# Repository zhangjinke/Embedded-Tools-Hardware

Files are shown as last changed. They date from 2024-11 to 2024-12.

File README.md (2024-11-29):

## 简介
多功能嵌入式调试工具，特性如下：
* 2 路 CAN 接口；
* 2 路 RS485 接口；
* 1 路 RS232 接口；
* 1 路 UART 接口；
* 1 个 X-Link；
* 1 个 OSJTAG(OSBDM)；
* 1 个 Micro SD 读卡器；
* 1 个 USB 集线器；
* USB 设备端、CAN、RS485、其它接口之间相互隔离；
* 支持拨码选择是否连接 CAN、RS485 的 120Ω 终端电阻；
* X-Link、OSJTAG 支持开关选择 Vref 引脚功能为连接目标板 Vref、输出 3.3V/5V；
* USB 主机、X-Link、OSJTAG 电源输出支持过流、短路以及防电流倒灌功能；

## 实物图
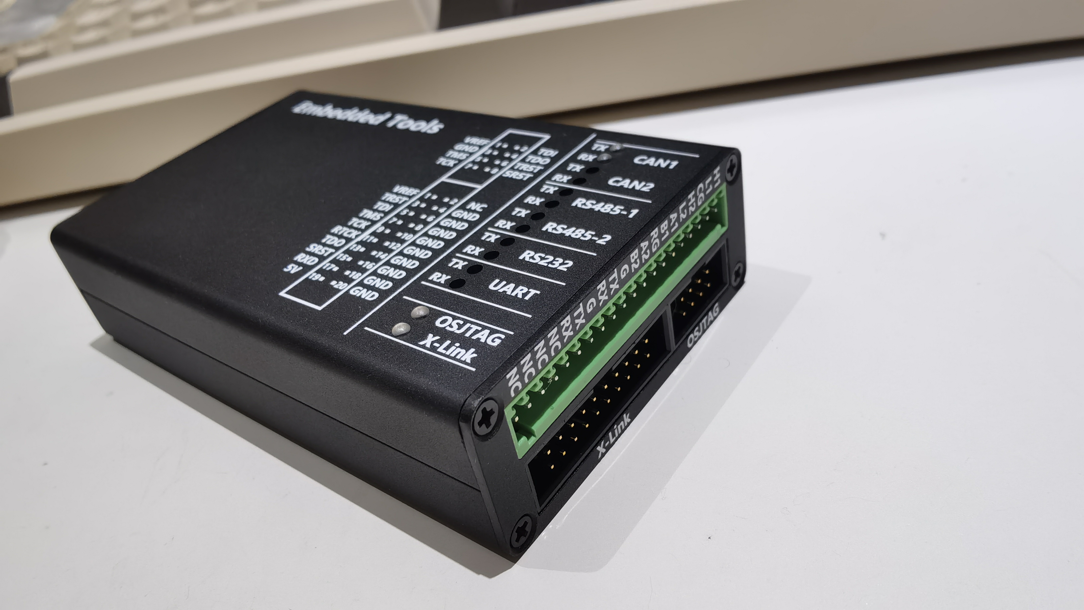
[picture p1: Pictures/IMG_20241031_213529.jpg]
实物图1

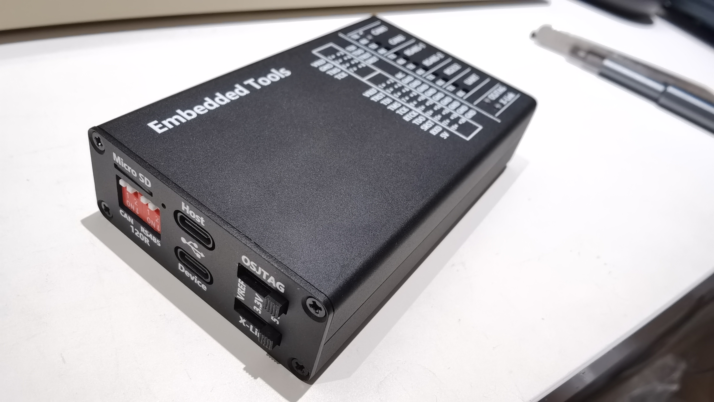
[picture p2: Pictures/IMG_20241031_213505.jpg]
实物图2


## 固件
1. X-Link 目前提供 V9 版模块，固件请在网上自行搜索；
2. OSJTAG 固件开源链接：[osbdm_hpm5301_software](https://github.com/zhangjinke/osbdm_hpm5301_software)；
3. CAN 固件请到 moonglow 大佬仓库搜索 1610 获取，上位机可使用 BUSMASTER。

## 注意事项
1. X-Link、OSJTAG、UART 的 IO 电平范围为 1.65V~5V，且 UART 接口电平与 OSJTAG 电平相同；
2. 连接 2 块主板的 1.27mm 间距，长度 11mm 的排针，请参考 IMG_20241118_211116.jpg 的方式，将长的部分缩短 0.5mm 左右；
3. 电脑端看到的串口 A、B、C、D 分别对应 RS485-1、RS485-2、RS232、UART；
4. 实测 USB 设备端电流 200+mA，若无法使用，请确保 USB 线质量与 USB 口供电能力；
3. USB 设备端隔离由于成本较高，可通过 0R 电阻替代；
4. SGM7222 为预留器件，请勿焊接。通过 R46、R47 焊接 0R 电阻替代。

## 后续计划
1. 增加 Linux 核心板、触摸显示屏、电池，实现离线烧录、升级、调试功能；
2. 增加 OSJTAG 固件功能，比如 DAPLink、USB 转 I2C、USB 转 SPI，模拟 2232 等；
3. 增加更多的 X-Link 模块。

## 声明
1. 您可以自由地对本项目进行修改和二次开发，但请务必在您的作品中注明原作者及原项目链接；
2. 本项目仅供个人、教育和非商业使用。**任何商业用途均需获得作者的事先书面许可**。

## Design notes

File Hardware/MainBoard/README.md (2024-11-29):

## 工程说明
使用嘉立创 EDA 专业版绘制。

## 更新日志

### 24/11/13 (V1.1.1)
- CH344Q RS485 RTC 上拉电阻 R17、R18 阻值从 100K 修改为 4.7K，修复 RTC 引脚未被配置为 RTC 功能，导致该引脚一直输出高电平的问题。

### 24/11/02 (V1.1)
1. 修复 Type-C 接口 DM、DP 反了的问题；
2. OSJTAG 通过增加 R52 修复运放输出震荡的问题，修复晶体负载电容 C4、C5 容值错误问题；
3. UART RX 上拉电阻 R29 从 100K 修改为 10K，降低被干扰的概率；
4. Communication PCB 宽度从 59.9mm 修改为 57.5mm，修复导光柱安装完成后，PCB 无法拆卸的问题；
5. X-Link&OSBDM PCB 在外壳卡槽内的区域，将丝印层修改为阻焊层，避免滑入卡槽内时丝印被刮脱落。

### 24/10/02 (V1.0)
- 初版。

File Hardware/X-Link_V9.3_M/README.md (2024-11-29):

## 工程说明
使用嘉立创 EDA 专业版绘制。

## 更新日志

### 24/11/03 (V1.0.1)
1. D3 修改为 BAT54C，Q2 修改为 KY6801，降低成本；
2. 注明 LED 型号。

### 24/11/04 (V1.0)
- 初版。

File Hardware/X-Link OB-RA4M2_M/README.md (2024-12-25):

## 工程说明
使用嘉立创 EDA 专业版绘制。

## 更新日志

### 24/12/25 (V1.1)
- 修复 MCU_SRST 未连接的问题。

### 24/12/16 (V1.0)
- 初版。

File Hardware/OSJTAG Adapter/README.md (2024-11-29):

## 工程说明
使用嘉立创 EDA 专业版绘制。

## 更新日志

### 24/11/13 (V1.1)
- 修复与上层端子干涉的问题。

### 24/11/02 (V1.0)
- 初版。

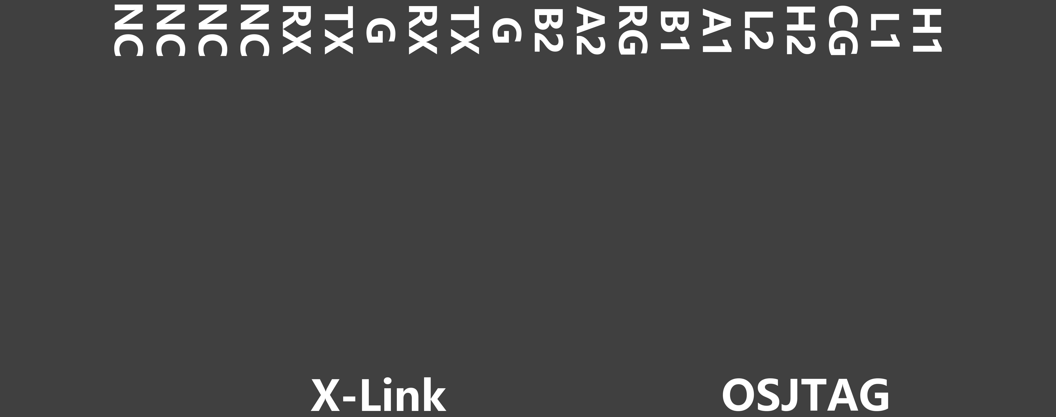
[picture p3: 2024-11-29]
Hardware/外壳/贴图/后面板贴图.png

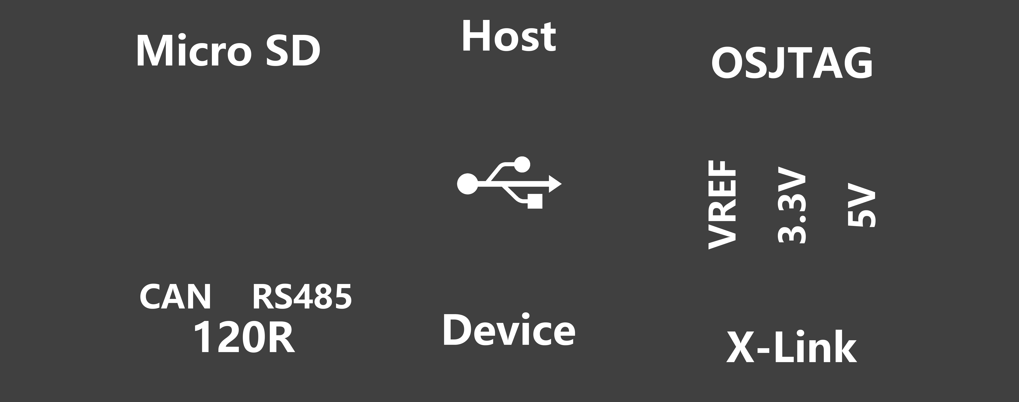
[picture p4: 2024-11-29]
Hardware/外壳/贴图/前面板贴图.png

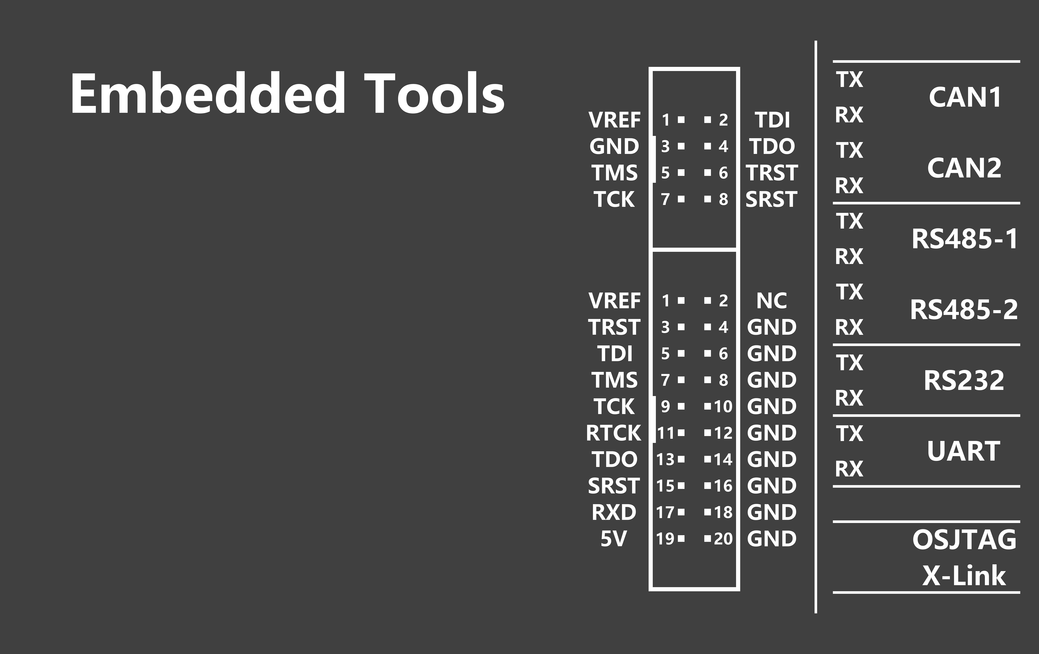
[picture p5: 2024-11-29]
Hardware/外壳/贴图/顶面贴图.png

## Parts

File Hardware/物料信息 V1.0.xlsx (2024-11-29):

No. | Quantity | 5套数量 | Comment | Footprint | Value | Designator | ManufacturerPart | Manufacturer | SupplierPart | Supplier | 焊接品牌 | 焊接型号 | 供应商 | 单价 | 价格
1 | 1 | 5 | 12MHz | CRYSTAL-SMD_4P-L2.5-W2.0-BL-A | 12MHz | X2 |  |  |  |  | 深圳市优信电子科技有限公司 | 12MHz ±10ppm 20pF 3225 | http://e.tb.cn/h.gG8uhOBYo26K7Oo?tk=8sAl39gV1uV | 0.19 | 0.19
2 | 1 | 5 | 12MHz | CRYSTAL-SMD_4P-L2.5-W2.0-BL-A | 12MHz | X3 |  |  |  |  | 深圳市优信电子科技有限公司 | 12MHz ±10ppm 20pF 3225 | http://e.tb.cn/h.gG8uhOBYo26K7Oo?tk=8sAl39gV1uV | 0.19 | 0.19
1 | 1 | 5 | 2.2uH | IND-SMD_L2.5-W2.0_MHCHL2520 | 2.2uH | L2 | FTC252012S2R2MBCA | cjiang(长江微电) | C5832372 |  | / | / | 立创商城 | 0.23256 | 0.23256
2 | 2 | 10 | 2.2uH | IND-SMD_L2.5-W2.0_MHCHL2520 | 2.2uH | L1,L2 | FTC252012S2R2MBCA | cjiang(长江微电) | C5832372 |  | / | / | 立创商城 | 0.23256 | 0.46512
1 | 1 | 5 | 24MHz | CRYSTAL-SMD_4P-L2.0-W1.6-BL-A | 24MHz | X1 |  |  |  |  | 扬兴晶振 | X201624MMB4SI | http://e.tb.cn/h.gG8tK4h0vi460dB?tk=m5nc39gWtUw | 0.26 | 0.26
1 | 1 | 5 | 4.7uH | IND-SMD_L2.5-W2.0 | 4.7uH | L1 | SWPA252012S4R7MT | Sunlord(顺络) | C87640 |  | 长江微电 | FTC252010S4R7MBCA | 立创商城 | 0.2182 | 0.2182
2 | 1 | 5 | 74HC245KAJ | TSSOP-20_L6.5-W4.4-P0.65-LS6.4-BL |  | U5 | 74HC245KAJ | FM(富满) | C19192982 |  | / | / | 立创商城 | 0.2686 | 0.2686
1 | 6 | 30 | 74LVC1T45DW-7 | SC-70-6_L2.2-W1.3-P0.65-LS2.1-BR |  | U4,U5,U6,U7,U8,U9 | 74LVC1T45DW-7 | DIODES(美台) | C168855 |  | / | / | 立创商城 | 0.3829 | 2.2974
2 | 2 | 10 | 74LVC1T45DW-7 | SC-70-6_L2.2-W1.3-P0.65-LS2.1-BR |  | U10,U11 | 74LVC1T45DW-7 | DIODES(美台) | C168855 |  | / | / | 立创商城 | 0.3829 | 0.7658
2 | 2 | 10 | 8MHz | CRYSTAL-SMD_4P-L3.2-W2.5-BL-A | 8MHz | X1,X2 |  |  |  |  | 创捷 | RL080002265 | 立创商城 | 0.3382 | 0.6764
2 | 1 | 5 | AO3401A | SOT-23_L2.9-W1.3-P1.90-LS2.4-BR |  | Q1 | AO3401A | AOS | C15127 |  | 杰盛微 | JSM2301S | 立创商城 | 0.050915 | 0.050915
2 | 2 | 10 | B0505S-1WR3 | PWRM-TH_B0503S-1WR2_S_1 |  | U4,U8 | B0505S-1WR3 | MORNSUN(金升阳) | C131038 |  |  |  |  | 2.52 | 5.04
3 | 1 | 5 | BAR43CFILM | SOT-23-3_L2.9-W1.3-P1.90-LS2.4-BR |  | D3 | BAR43CFILM | ST(意法半导体) | C69290 |  | 杰盛微 | BAT54C | 立创商城 | 0.042423 | 0.042423
2 | 6 | 30 | BLUE | LED0603 |  | LED1,LED3,LED6,LED8,LED10,LED12 |  |  |  |  | 成兴光 | XL-1608UBC-04 | 立创商城 | 0.02034 | 0.12204
2 | 1 | 5 | BX-PM1.27-2-5PU | HDR-TH_10P-P1.27-V-F-R2-C5-S1.27_1 |  | P2 | BX-PM1.27-2-5PU | Bossie(博锡) | C18078163 |  | 深圳市优信电子科技有限公司 | 1.27 双排母 2*50P | http://e.tb.cn/h.gGBZZw8JrdaCuqG?tk=1dFH395rqjm | 0.275 | 0.275
2 | 1 | 5 | CA-IS3742HB | SSOP-16_L4.9-W3.9-P0.64-LS6.0-BL |  | U3 | CA-IS3742HB | Chipanalog(川土微) | C7370896 |  | / | / | 立创商城 | 3.47 | 3.47
2 | 1 | 5 | CA-IS3762HB | SSOP-16_L4.9-W3.9-P0.64-LS6.0-BL-1 |  | U7 | CA-IS3762HB | Chipanalog(川土微) | C19723482 |  | / | / | 立创商城 | 5.06 | 5.06
1 | 1 | 5 | CH334R | QSOP-16_L4.9-W3.9-P0.64-LS6.0-BL |  | U10 | CH334R | WCH(南京沁恒) | C4154405 |  | / | / | http://e.tb.cn/h.gtD9xLTc9HWW0nF?tk=pGPC39gR36E | 1.5 | 1.5
2 | 1 | 5 | CH334R | QSOP-16_L4.9-W3.9-P0.64-LS6.0-BL |  | U19 | CH334R | WCH(南京沁恒) | C4154405 |  | / | / | http://e.tb.cn/h.gtD9xLTc9HWW0nF?tk=pGPC39gR36E | 1.5 | 1.5
2 | 1 | 5 | CH344Q | LQFP-48_L7.0-W7.0-P0.50-LS9.0-BL |  | U6 | CH344Q | WCH(南京沁恒) | C2988084 |  | / | / | http://e.tb.cn/h.gGYxo0BpgagSMRt?tk=JBjL39giDhR | 10.27 | 10.27
2 | 1 | 5 | ESDA5V3L | SOT-23-3_L2.9-W1.6-P1.90-LS2.8-BR |  | U15 | ESDA5V3L |  |  |  | ST | ESDA6V1L | 立创商城 | 0.5332 | 0.5332
3 | 1 | 5 | FDC6312P | SOT-23-6_L2.9-W1.6-P0.95-LS2.8-BR |  | Q2 | FDC6312P | onsemi(安森美) | C241767 |  | 韩景元 | KY6801 | 立创商城 | 0.2354 | 0.2354
2 | 12 | 60 | FUSE0805 | F0805 |  | F1,F2,F3,F4,F5,F6,F7,F8,F9,F10,F11,F12 |  |  |  |  | 比诺星 | SMD0805-010C-15V | 立创商城 | 0.10412 | 1.24944
2 | 1 | 5 | GL823K-HCY04 | SSOP-16_L4.9-W3.9-P0.64-LS6.0-BL |  | U18 | GL823K-HCY04 | GENESYS(创惟) | C284879 |  | / | / | http://e.tb.cn/h.gGYxcwATD4O97e4?tk=jXfs39gi9vk MF7997 | 1.15 | 1.15
2 | 1 | 5 | HDR1x5_1.27 | HDR-TH_5P-P1.27-V-M |  | P1 |  |  |  |  |  |  |  |  | 0
3 | 1 | 5 | HDR1x5_1.27 | HDR-TH_5P-P1.27-V-M |  | P3 |  |  |  |  |  |  |  |  | 0
1 | 1 | 5 | HDR1x7_1.27 | HDR-TH_7P-P1.27-V-M-1 |  | P3 |  |  |  |  |  |  |  |  | 0
3 | 1 | 5 | HDR2x10_1.27 | HDR-TH_20P-P1.27-V-M-R2-C10-S1.27 |  | P2 |  |  |  |  | 怡兴达数码专营店 | 间距1.27mm/针长11mm 2*50P | http://e.tb.cn/h.gG8eFk0z1i0zUFU?tk=9gg2395n4TH | 0.72 | 0.72
1 | 1 | 5 | HDR2x10_1.27_SMD | HDR-SMD_20P-P1.27-V-M-R2-C10-LS5.5 |  | P2 |  |  |  |  | 深圳市优信电子科技有限公司 | 双排贴片 镀金 2*50P | http://e.tb.cn/h.gGBZZw8JrdaCuqG?tk=1dFH395rqjm | 0.24 | 0.24
1 | 2 | 10 | HDR2x16_1.27 | HDR-TH_32P-P1.27-V-M-R2-C16-S1.27 |  | U15,U16 |  |  |  |  | 怡兴达数码专营店 | 间距1.27mm/针长11mm 2*50P | http://e.tb.cn/h.gG8eFk0z1i0zUFU?tk=9gg2395n4TH | 1.2 | 2.4
1 | 1 | 5 | HDR2x5_1.27_1 | HDR-TH_10P-P1.27-V-M-R2-C5-S1.27_1 |  | P4 |  |  |  |  | 怡兴达数码专营店 | 间距1.27mm/针长11mm 2*50P | http://e.tb.cn/h.gG8eFk0z1i0zUFU?tk=9gg2395n4TH | 0.36 | 0.36
3 | 1 | 5 | HDR2x8_1.27 | HDR-TH_16P-P1.27-V-M-R2-C8-S1.27-1 |  | P1 |  |  |  |  | 怡兴达数码专营店 | 间距1.27mm/针长11mm 2*50P | http://e.tb.cn/h.gG8eFk0z1i0zUFU?tk=9gg2395n4TH | 0.6 | 0.6
1 | 1 | 5 | HDR2x8_1.27_SMD | HDR-SMD_16P-P1.27-V-M-R2-C8-LS5.5 |  | P1 |  |  |  |  | 深圳市优信电子科技有限公司 | 双排贴片 镀金 2*50P | http://e.tb.cn/h.gGBZZw8JrdaCuqG?tk=1dFH395rqjm | 0.2 | 0.2
1 | 1 | 5 | HPM5301IEG1 | QFN-48_L6.0-W6.0-P0.4-BL-EP4.2 |  | U2 |  |  |  |  | / | / | http://e.tb.cn/h.gG8zsUPNutN8KXw?tk=Koz539g77Q9 | 8.5 | 8.5
1 | 1 | 5 | IDC2x10_SMD | IDC-SMD_20P-P2.54 |  | P6 |  |  |  |  | 精工南士 | DC3-20P 直针 简牛 | http://e.tb.cn/h.gtD8Dcz8nh2YK2G?tk=6Xnf39ghhj2 | 0.8 | 0.8
1 | 1 | 5 | IDC2x4_SMD | IDC-SMD_8P-P2.54 |  | P5 |  |  |  |  | 精工南士 | DC3-8P 直针 简牛 | http://e.tb.cn/h.gGBqdUiuMef7D32?tk=knkB39gTxVA | 1 | 1
1 | 1 | 5 | ISOUSB211DPR | SSOP-28_L10.3-W7.5-P0.65-LS10.3-BL |  | U12 | ISOUSB211DPR | TI(德州仪器) | C5772877 |  | / | / | https://www.zxjian.com/search?searchContent=ISOUSB211DPR | 34.32 | 34.32
2 | 1 | 5 | KF2EDGV-2.5-20P | CONN-TH_20P-P2.50_KF2EDGV-2.5-20P_SMD |  | CN1 | KF2EDGV-2.5-20P | KEFA(科发) |  |  | / | / | http://e.tb.cn/h.gGBpbUBK6ho59aD?tk=On6O39gg8iQ | 9 | 9
1 | 1 | 5 | LED1615 | LED1615 |  | D1 |  |  |  |  |  |  |  | 0.1 | 0.1
2 | 2 | 10 | LED1615 | LED1615 |  | D5,D6 |  |  |  |  |  |  |  | 0.1 | 0.2
3 | 1 | 5 | LED1615 | LED1615 |  | D1 |  |  |  |  |  |  |  | 0.1 | 0.1
2 | 1 | 5 | LMV358AIDGKR | VSSOP-8_L3.0-W3.0-P0.65-LS5.0-BL |  | U19 | LMV358AIDGKR | TI(德州仪器) | C408974 |  | / | / | 立创商城 | 0.363675 | 0.363675
2 | 1 | 5 | LMV358AIDGKR | VSSOP-8_L3.0-W3.0-P0.65-LS5.0-BL |  | U24 | LMV358AIDGKR | TI(德州仪器) | C408974 | LCSC | / | / | 立创商城 | 0.363675 | 0.363675
3 | 1 | 5 | LMV358AIDGKR | VSSOP-8_L3.0-W3.0-P0.65-LS5.0-BL |  | U9 | LMV358AIDGKR | TI(德州仪器) | C408974 |  | / | / | 立创商城 | 0.363675 | 0.363675
1 | 4 | 20 | NC | R1206 | NC | R42,R43,R44,R45 |  |  |  |  |  |  |  |  | 0
1 | 2 | 10 | NC | R0402 | NC | R46,R47 |  |  |  |  |  |  |  |  | 0
3 | 1 | 5 | NC | R0603 | NC | R47 |  |  |  |  |  |  |  |  | 0
2 | 2 | 10 | PM1.27-2x16 | HDR-TH_32P-P1.27-V-F-R2-C16-S1.27 |  | P3,P4 |  |  |  |  | 深圳市优信电子科技有限公司 | 1.27 双排母 2*50P | http://e.tb.cn/h.gGBZZw8JrdaCuqG?tk=1dFH395rqjm | 1.1 | 2.2
2 | 1 | 5 | SDT23C712L02 | SOT-23-3_L2.9-W1.6-P1.90-LS2.8-BR |  | U14 | SDT23C712L02 |  |  |  | KUU | SM15C | 立创商城 | 0.24225 | 0.24225
2 | 1 | 5 | SGM7222YMS10/TR | MSOP-10_L3.0-W3.0-P0.50-LS5.0-BL |  | U14 | SGM7222YMS10/TR | SGMICRO(圣邦微) | C113292 |  | / | / | http://e.tb.cn/h.gGYKvP2s6YJ0WTn?tk=oXOS39gW0AS | 0.89 | 0.89
1 | 1 | 5 | SI2302A | SOT-23-3_L2.9-W1.3-P1.90-LS2.4-BR |  | Q1 | SI2302A | UMW(友台半导体) | C347483 |  | 杰盛微 | JSM2302 | 立创商城 | 0.025185 | 0.025185
2 | 2 | 10 | SIT1057TK/3 | DFN-8_L3.0-W3.0-P0.65-BL-EP-1 |  | U1,U2 | SIT1057TK/3 | SIT(芯力特) | C5382538 |  | / | SIT1044QTK/3 | http://e.tb.cn/h.gG8xwxTs4wh8V0T?tk=FNJl39g52lN | 1.57 | 3.14
2 | 2 | 10 | SIT3088ETK | DFN-8_L3.0-W3.0-P0.65-BL-EP |  | U12,U13 | SIT3088ETK | SIT(芯力特) | C601076 |  | / | / | http://e.tb.cn/h.gtDSMO9yWGzUPp2?tk=eQNd39gU2ci | 0.7 | 1.4
2 | 2 | 10 | SM712 | SOT-23-3_L2.9-W1.6-P1.90-LS2.8-BR |  | U16,U17 | SM712 |  |  |  | 静芯微 | SM712.TCT-ES | 立创商城 | 0.0982 | 0.1964
2 | 2 | 10 | SM712 | SOT-23-3_L2.9-W1.6-P1.90-LS2.8-BR |  | D1,D2 | SM712 | MDD | C502564 |  | 静芯微 | SM712.TCT-ES | 立创商城 | 0.0982 | 0.1964
1 | 2 | 10 | SMQP-02R-TP | SW-TH_4P-P2.54_SMQP-02R-TP |  | U17,U18 | SMQP-02R-TP | SMSwitch | C5299482 |  |  |  |  | 1.7117 | 3.4234
3 | 7 | 35 | SN74LVC2T45DCUR | VSSOP-8_L2.4-W2.1-P0.50-LS3.2-BR |  | U2,U3,U4,U5,U6,U7,U8 | SN74LVC2T45DCUR | TI(德州仪器) | C15741 | LCSC |  |  |  | 1.4 | 9.8
2 | 1 | 5 | SP3232EEY-L/TR | TSSOP-16_L5.0-W4.4-P0.65-LS6.4-BL |  | U9 | SP3232EEY-L/TR | MaxLinear(迈凌) | C13482 |  | / | / | 立创商城 | 1.4102 | 1.4102
1 | 1 | 5 | SS23H37L4 | SW-TH_SS23H37LX_SMD |  | SW1 | SS23H37L4 | XKBConnectivity(中国星坤) | C883268 |  | / | / | 立创商城 | 1.8854 | 1.8854
2 | 1 | 5 | SS23H37L4 | SW-TH_SS23H37LX_SMD |  | SW1 | SS23H37L4 | XKBConnectivity(中国星坤) | C883268 |  | / | / | 立创商城 | 1.8854 | 1.8854
3 | 1 | 5 | STM32F205RCT6 | LQFP-64_L10.0-W10.0-P0.50-LS12.0-BL |  | U1 | STM32F205RCT6 | ST(意法半导体) | C47520 |  |  |  |  | 24 | 24
2 | 1 | 5 | STM32F405RGT6 | LQFP-64_L10.0-W10.0-P0.50-LS12.0-BL |  | U23 | STM32F405RGT6 | ST(意法半导体) | C15742 |  | / | / | http://e.tb.cn/h.gGBNSX9pXcJlqrS?tk=GWVA39gUUjT | 11.97 | 11.97
2 | 2 | 10 | SY6280AAC | SOT-23-5_L3.0-W1.7-P0.95-LS2.8-BL |  | U1,U3 | SY6280AAC | silergy(矽力杰) | C55136 |  | / | / | http://e.tb.cn/h.gGYpF9LmazMhy0t?tk=4L9W39g2rNn | 0.39 | 0.78
2 | 1 | 5 | SY6280AAC | SOT-23-5_L3.0-W1.7-P0.95-LS2.8-BL |  | U22 | SY6280AAC | silergy(矽力杰) | C55136 |  | / | / | http://e.tb.cn/h.gGYpF9LmazMhy0t?tk=4L9W39g3rNn | 0.39 | 0.39
2 | 1 | 5 | TFPUSH | TF-SMD_TF-PUSH |  | CARD1 | TFPUSH | SHOUHAN(首韩) | C393941 |  | / | / | 立创商城 | 0.2953 | 0.2953
1 | 1 | 5 | TLV62568DBVR | SOT-23-5_L3.0-W1.7-P0.95-LS2.8-BR |  | U11 | TLV62568DBVR | TI(德州仪器) | C163219 |  | / | / | http://e.tb.cn/h.gGYoAijcOZGUYAO?tk=V5jb39gXJOI | 0.22 | 0.22
2 | 2 | 10 | TLV62568DBVR | SOT-23-5_L3.0-W1.7-P0.95-LS2.8-BR |  | U20,U21 | TLV62568DBVR | TI(德州仪器) | C163219 |  | / | / | http://e.tb.cn/h.gGYoAijcOZGUYAO?tk=V5jb39gXJOI | 0.22 | 0.44
1 | 1 | 5 | USB31-TYPEC-16X7C-1FS | USB-SMD_USB31-TYPEC-16X7C-1FS |  | USB1 | USB31-TYPEC-16X7C-1FS | XKBConnection(中国星坤) | C2880667 |  | / | / | http://e.tb.cn/h.gtDWSV4pChgk9Iz?tk=zA9P39gcN4s CA6496 | 3.8 | 3.8
2 | 1 | 5 | USB31-TYPEC-16X7C-1FS | USB-SMD_USB31-TYPEC-16X7C-1FS |  | USB1 | USB31-TYPEC-16X7C-1FS | XKBConnection(中国星坤) | C2880667 |  | / | / | http://e.tb.cn/h.gtDWSV4pChgk9Iz?tk=zA9P39gcN4s CA6496 | 3.8 | 3.8
1 | 1 | 5 | USBLC6-2SC6 | SOT-23-6_L2.9-W1.6-P0.95-LS2.8-BL |  | D3 | USBLC6-2SC6 | UMW(友台半导体) | C2687116 |  | 东沃 | USBLC6-2SC6 | 立创商城 | 0.1044 | 0.1044
2 | 1 | 5 | USBLC6-2SC6 | SOT-23-6_L2.9-W1.6-P0.95-LS2.8-BL |  | D4 | USBLC6-2SC6 | UMW(友台半导体) | C2687116 |  | 东沃 | USBLC6-2SC6 | 立创商城 | 0.1044 | 0.1044
1 | 1 | 5 | VRB0505S-5WR3 | PWRM-TH_7P-L22.0-W9.5-P2.54_VRB0505S-5WR3_ST |  | U13 | VRB0505S-5WR3 | MORNSUN(金升阳) | C5189717 |  | kcut旗舰店 | VRB0505S-6WR3 | http://e.tb.cn/h.gGyyCbm65PxT9SJ?tk=wbKx395qVMP | 17.5 | 17.5
2 | 6 | 30 | YELLOW | LED0603 |  | LED2,LED4,LED7,LED9,LED11,LED13 |  |  |  |  | 拓展光电 | TZ-P2-0603YGTCS1-0.6T | 立创商城 | 0.0468 | 0.2808
2 | 1 | 1 | 8P排线 | 1.27 |  |  |  |  |  |  | 深圳致远电子企业店 | 100mm | http://e.tb.cn/h.T23iBy0s1SgjbUQ?tk=RUI63GBSX9R | 0.2 | 0.2
2 | 14 | 70 | 导光柱LDT2.0x6 | 开孔φ1.95-2.0 |  |  |  |  |  |  | 导光柱生产工厂店 | 6mm | http://e.tb.cn/h.T21eHfGMxfLbz30?tk=4rl93GBURiF | 0.22 | 3.08
 | 1 | 5 | 铝型材壳体 | 分体式K30(100x63x25) |  |  |  |  |  |  | 嘉立创FA-铝合金壳体 | 分体式K30(100x63x25) | https://ke.jlcfa.com/share/DAFCFDD64CEA470E9EB28F21D9953762/371638437327007745 访问密码：5T8A【嘉立创FA铝合金壳体】Embedded Tools | 35 | 35
 |  |  |  |  |  |  |  |  |  |  |  |  |  | 总价 | 224.353058 | 172.533058

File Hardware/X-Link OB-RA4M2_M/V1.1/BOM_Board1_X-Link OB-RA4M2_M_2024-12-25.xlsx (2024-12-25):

No. | Quantity | Comment | Footprint | Value | Designator | Manufacturer Part | Manufacturer | Supplier Part | Supplier
1 | 1 | 2.2uF | C0402 | 2.2uF | C8
2 | 2 | 10pF | C0402 | 10pF | C1,C2
3 | 16 | 100nF | C0402 | 100nF | C3,C4,C5,C6,C7,C9,C10,C11,C12,C13,C14,C15,C16,C17,C18,C19
4 | 1 | 12MHz | CRYSTAL-SMD_4P-L2.5-W2.0-BL-A | 12MHz | X1
5 | 1 | HDR1x5_1.27 | HDR-TH_5P-P1.27-V-M |  | P3
6 | 1 | HDR2x8_1.27 | HDR-TH_16P-P1.27-V-M-R2-C8-S1.27-1 |  | P1
7 | 1 | HDR2x10_1.27 | HDR-TH_20P-P1.27-V-M-R2-C10-S1.27 |  | P2
8 | 1 | WHITE | LED0603 |  | LED1
9 | 1 | R7FA4M2AB3CFL#AA0 | LQFP-48_L7.0-W7.0-P0.50-LS9.0-BL |  | U2 | R7FA4M2AB3CFL#AA0 | RENESAS(瑞萨)/IDT | C3230219 | LCSC
10 | 1 | 1K | R0402 | 1K | R14
11 | 6 | 10K | R0402 | 10K | R1,R4,R5,R6,R8,R10
12 | 1 | 12K | R0402 | 12K | R7
13 | 2 | 27R | R0402 | 27R | R2,R3
14 | 7 | 100R | R0402 | 100R | R24,R25,R26,R27,R28,R29,R30
15 | 7 | 200K | R0402 | 200K | R9,R13,R21,R22,R23,R31,R32
16 | 6 | 220R | R0402 | 220R | R15,R16,R17,R18,R19,R20
17 | 1 | NC | R0402 | NC | R11
18 | 1 | 100R | R0805 | 100R | R12
19 | 1 | SN74LVC1G3157DCKR | SC70-6_L2.1-W1.3-P0.65-LS2.3-BL |  | U4 | SN74LVC1G3157DCKR | UMW(友台半导体) | C2681224 | LCSC
20 | 4 | SN74LVC1T45DC(LX) | SC-70-6_L2.2-W1.3-P0.65-LS2.1-BR |  | U6,U7,U8,U9 | SN74LVC1T45DC(LX) | LX(灵星芯微) | C22469932 | LCSC
21 | 1 | 1N5819WT | SOD-523_L1.2-W0.8-LS1.6-RD |  | D1 | 1N5819WT | Slkor(萨科微) | C5185918 | LCSC
22 | 1 | LMV321 | SOT-23-5_L2.9-W1.6-P0.95-LS2.8-BR |  | U3 | LMV321
23 | 1 | SY6280AAC | SOT-23-5_L3.0-W1.7-P0.95-LS2.8-BL |  | U1 | SY6280AAC | silergy(矽力杰) | C55136 | LCSC
24 | 2 | HXY1012CI | SOT-523-3_L1.6-W0.8-P0.50-LS1.6-BR |  | Q1,Q2 | HXY1012CI | HXY MOSFET(华轩阳电子) | C5148644 | LCSC
25 | 1 | PI4ULS5V202XVEX | UDFN-8_L1.6-W1.2-P0.40-BL |  | U10 | PI4ULS5V202XVEX | DIODES(美台) | C2677370 | LCSC

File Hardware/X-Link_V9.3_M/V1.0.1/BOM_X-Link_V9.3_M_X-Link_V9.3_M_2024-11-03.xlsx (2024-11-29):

No. | Quantity | Comment | Footprint | Value | Designator | Manufacturer Part | Manufacturer | Supplier Part | Supplier
1 | 4 | 2.2uF | C0603 | 2.2uF | C8,C9,C11,C16
2 | 2 | 10pF | C0603 | 10pF | C5,C6
3 | 18 | 100nF | C0603 | 100nF | C1,C2,C3,C4,C7,C10,C12,C13,C14,C15,C17,C18,C19,C20,C21,C22,C23,C24
4 | 1 | 12MHz | CRYSTAL-SMD_4P-L3.2-W2.5-BL-A | 12MHz | X1
5 | 1 | HDR1x5_1.27 | HDR-TH_5P-P1.27-V-M |  | P3
6 | 1 | HDR2x8_1.27 | HDR-TH_16P-P1.27-V-M-R2-C8-S1.27-1 |  | P1
7 | 1 | HDR2x10_1.27 | HDR-TH_20P-P1.27-V-M-R2-C10-S1.27 |  | P2
8 | 1 | XL-1615SURSYGC | LED1615 |  | D1 | XL-1615SURSYGC | XINGLIGHT(成兴光) | C965838 | LCSC
9 | 1 | STM32F205RCT6 | LQFP-64_L10.0-W10.0-P0.50-LS12.0-BL |  | U1 | STM32F205RCT6 | ST(意法半导体) | C47520 | LCSC
10 | 2 | 1K | R0603 | 1K | R6,R7
11 | 8 | 2.2K | R0603 | 2.2K | R2,R3,R8,R9,R10,R11,R13,R14
12 | 5 | 10K | R0603 | 10K | R4,R5,R17,R18,R21
13 | 1 | 68R | R0603 | 68R | R37
14 | 5 | 100K | R0603 | 100K | R1,R15,R16,R19,R42
15 | 7 | 100R | R0603 | 100R | R12,R20,R34,R35,R36,R38,R39
16 | 7 | 220K | R0603 | 220K | R43,R44,R45,R46,R48,R49,R50
17 | 12 | 220R | R0603 | 220R | R24,R25,R26,R27,R28,R29,R30,R31,R32,R33,R40,R41
18 | 1 | NC | R0603 | NC | R47
19 | 2 | 1R | R0805 | 1R | R22,R23
20 | 1 | B5819WS | SOD-323_L1.8-W1.3-LS2.5-RD |  | D2 | B5819WS | CJ(江苏长电/长晶) | C22624 | LCSC
21 | 1 | BAT54C | SOT-23-3_L2.9-W1.3-P1.90-LS2.4-BR |  | D3 | BAT54C | JSMSEMI(杰盛微) | C916424 | LCSC
22 | 1 | JSM2302 | SOT-23-3_L2.9-W1.3-P1.90-LS2.4-BR |  | Q1 | JSM2302 | JSMSEMI(杰盛微) | C916403 | LCSC
23 | 1 | KY6801 | SOT-23-6_L2.9-W1.6-P0.95-LS2.8-BR |  | Q2 | KY6801 | KY(韩景元) | C3029283 | LCSC
24 | 7 | SN74LVC2T45DCUR | VSSOP-8_L2.4-W2.1-P0.50-LS3.2-BR |  | U2,U3,U4,U5,U6,U7,U8 | SN74LVC2T45DCUR | TI(德州仪器) | C15741 | LCSC
25 | 1 | LMV358AIDGKR | VSSOP-8_L3.0-W3.0-P0.65-LS5.0-BL |  | U9 | LMV358AIDGKR | TI(德州仪器) | C408974 | LCSC

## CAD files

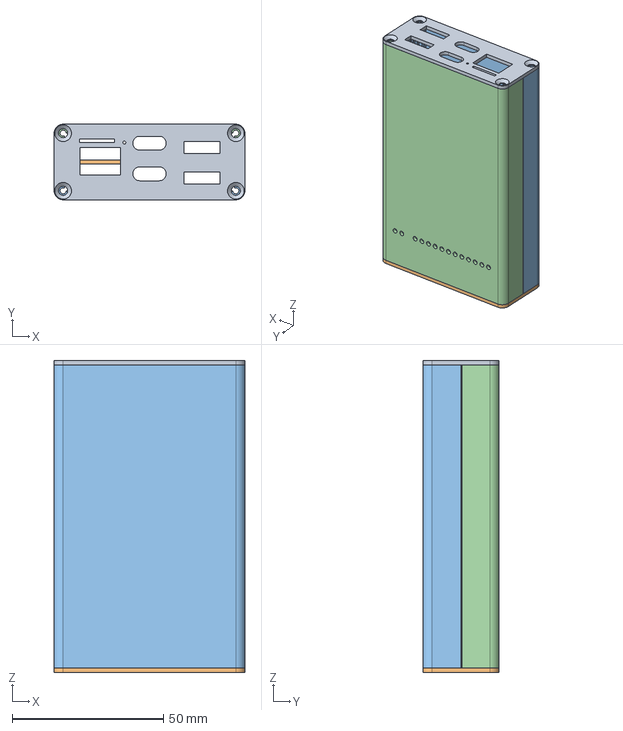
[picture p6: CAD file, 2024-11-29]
Hardware/外壳/分体式K30_1728622400uj7h.stp
63.0 x 25.0 x 103.0 mm

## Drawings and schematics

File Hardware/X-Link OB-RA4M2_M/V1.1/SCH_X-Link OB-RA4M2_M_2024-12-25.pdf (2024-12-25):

# Vref缓冲

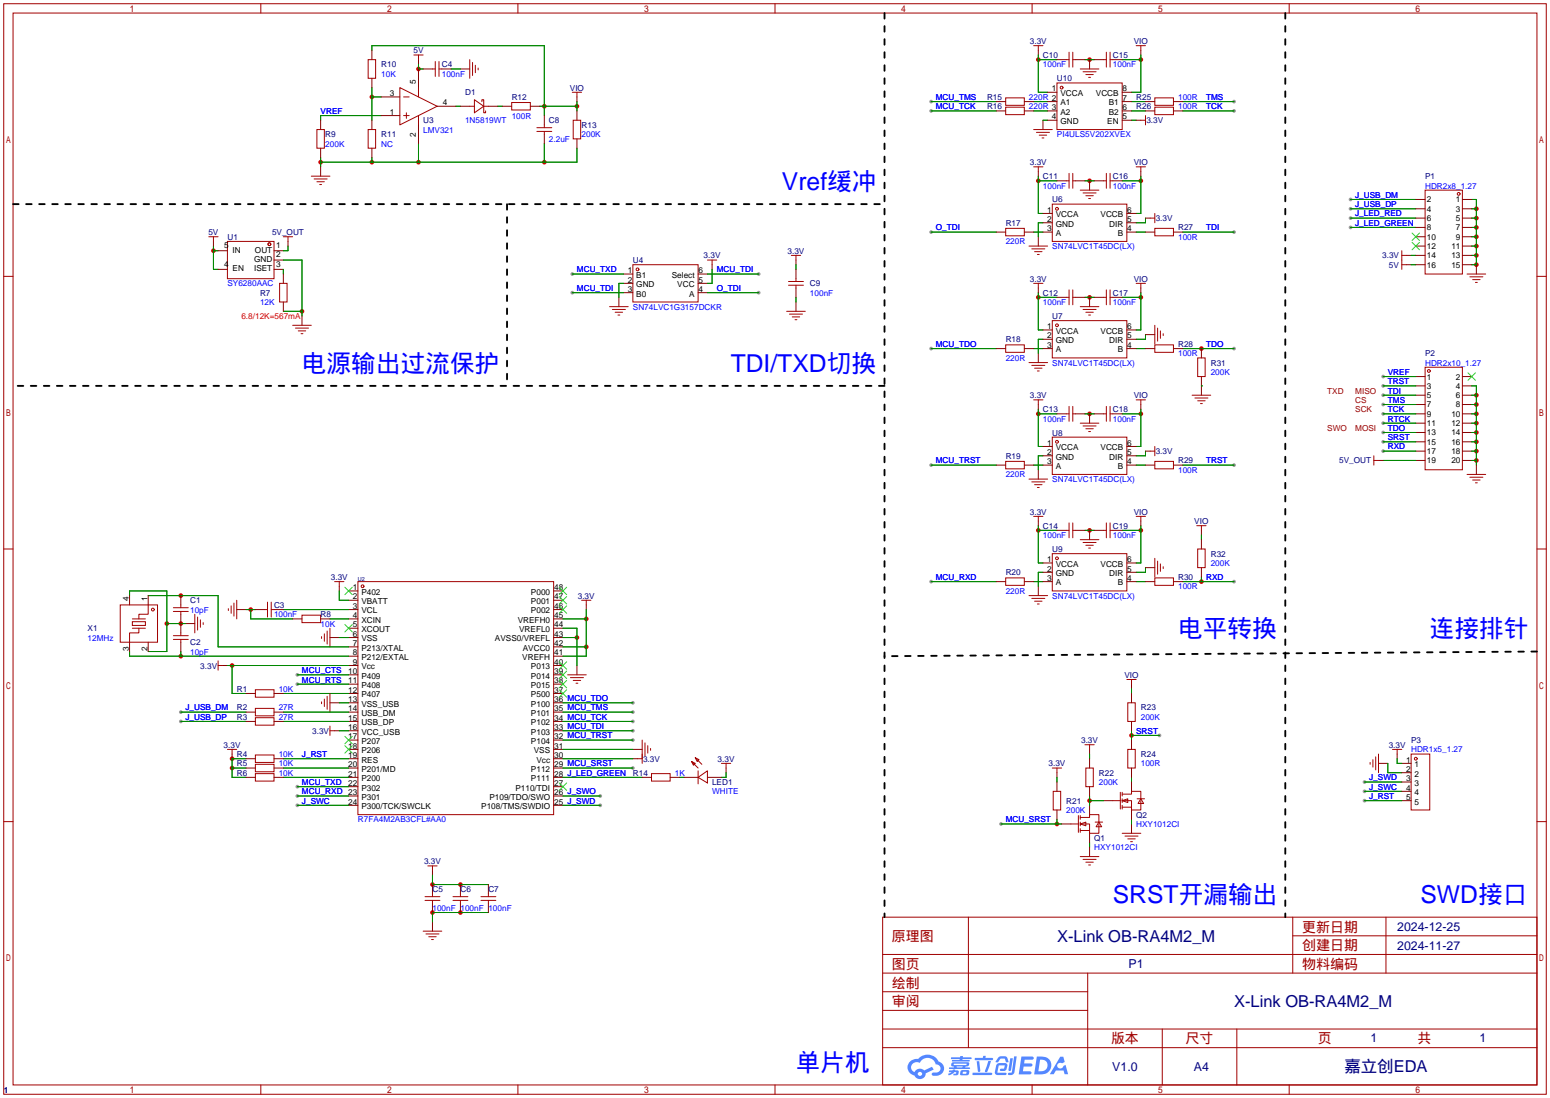
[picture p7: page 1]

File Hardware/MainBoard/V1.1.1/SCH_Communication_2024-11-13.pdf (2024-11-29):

# CAN1

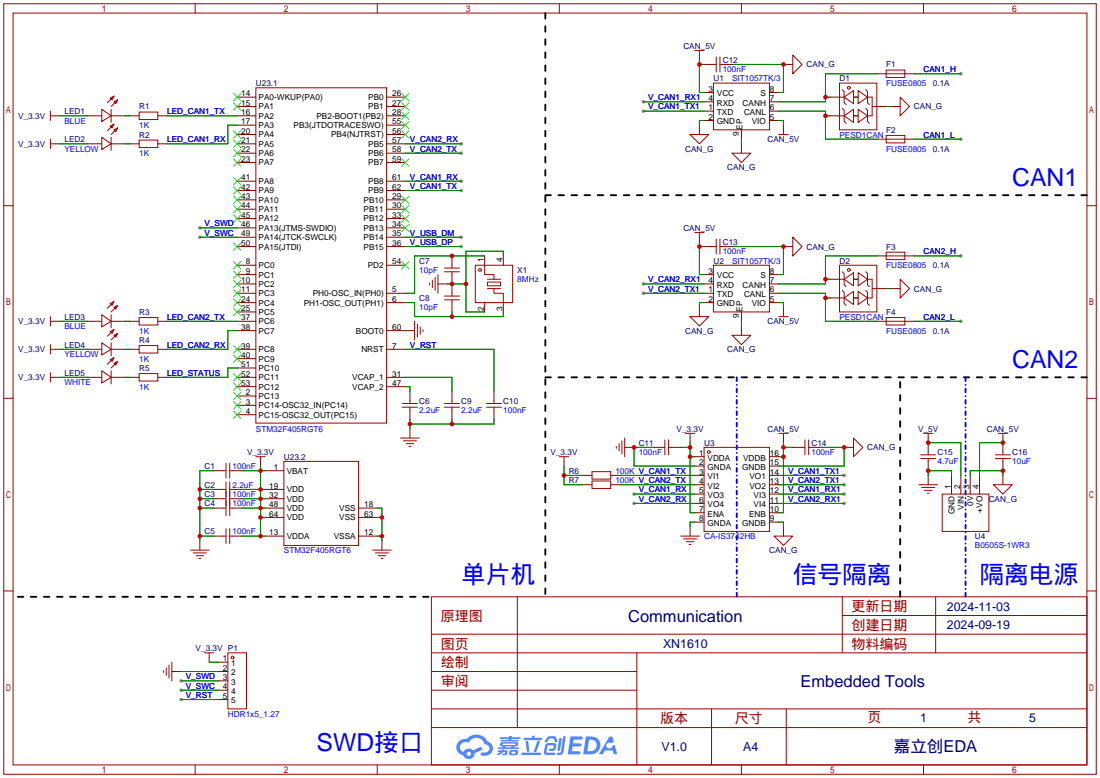
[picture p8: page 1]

C3 | 100nF
C4 | 100nF

# RS485_1

# 信号隔离

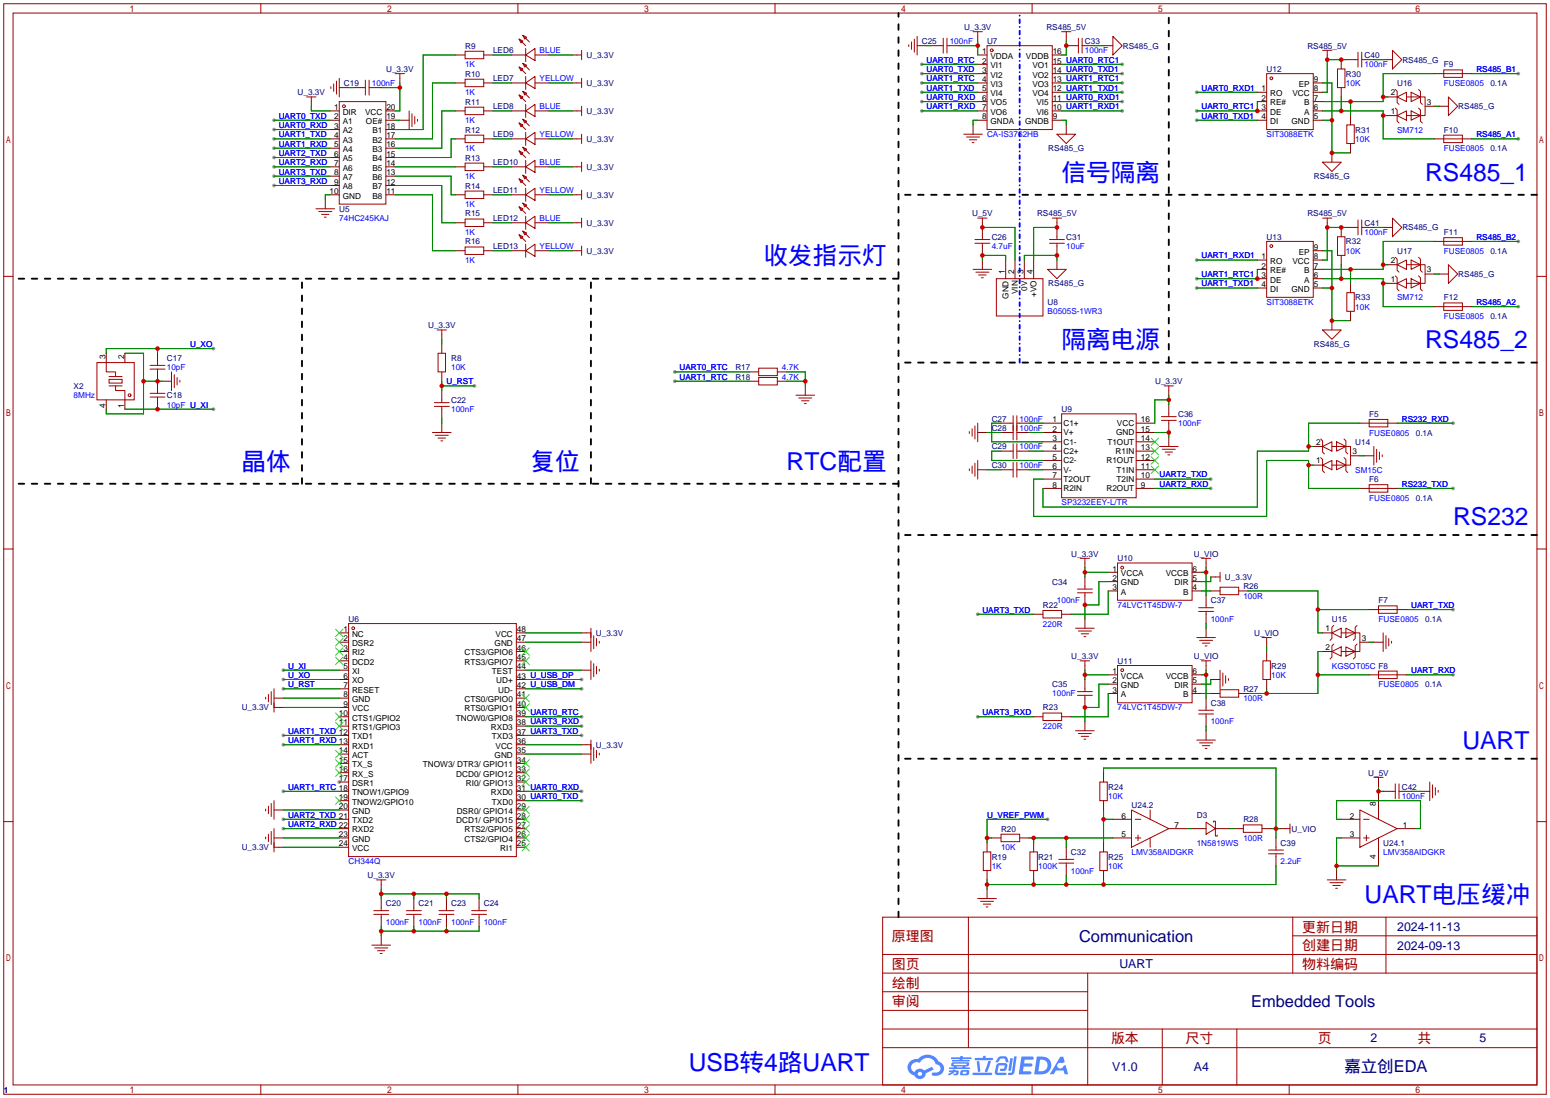
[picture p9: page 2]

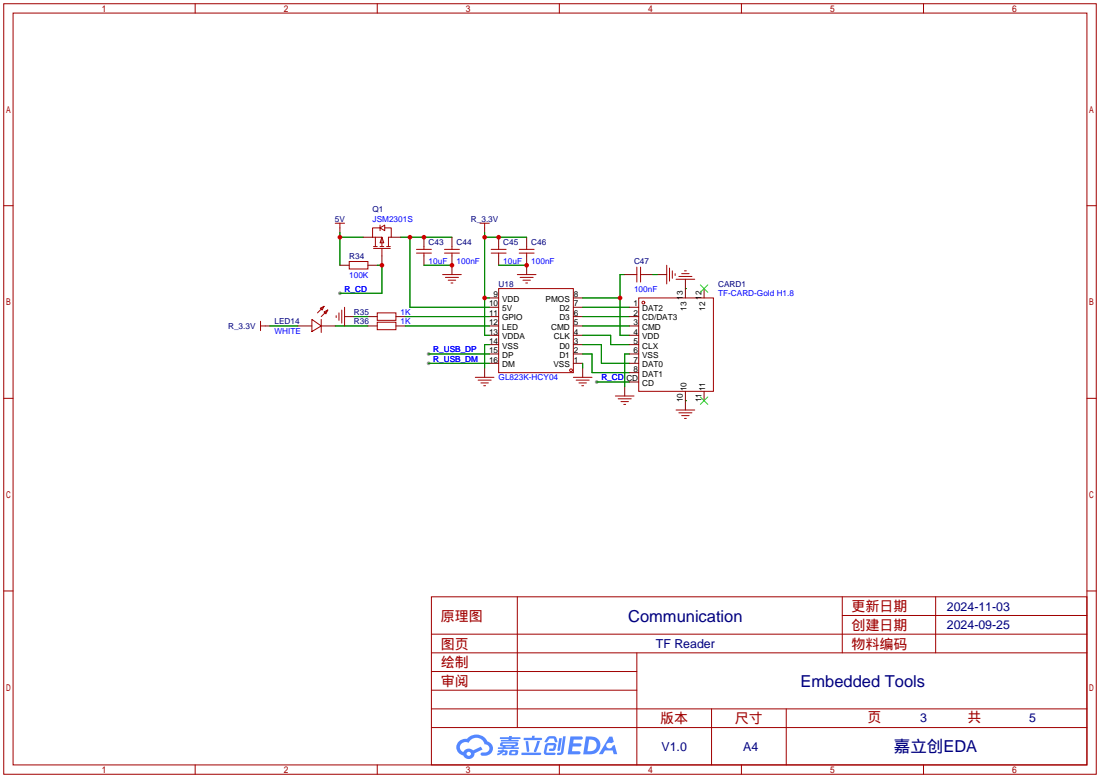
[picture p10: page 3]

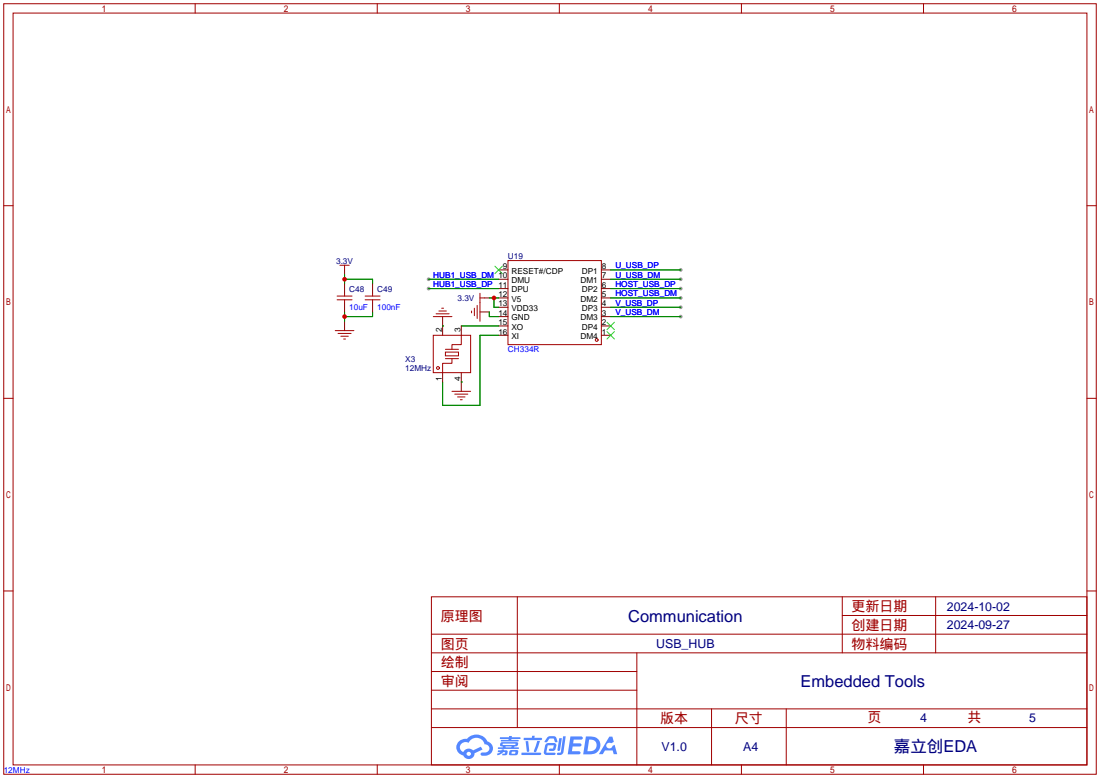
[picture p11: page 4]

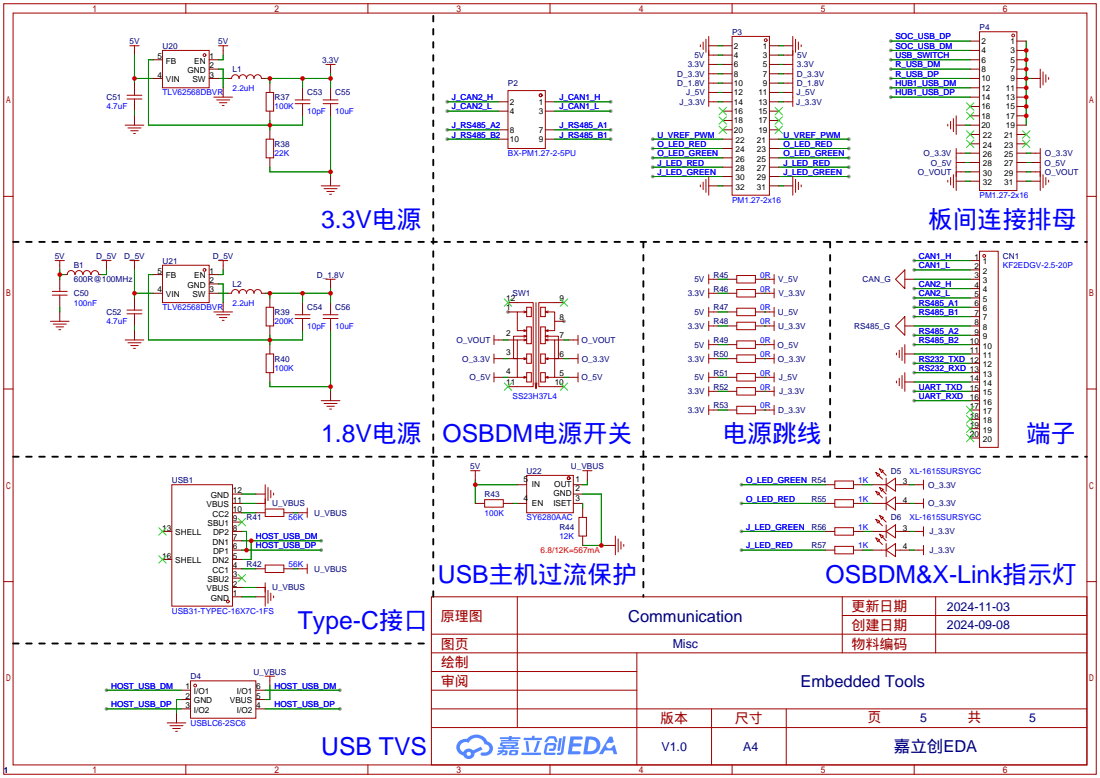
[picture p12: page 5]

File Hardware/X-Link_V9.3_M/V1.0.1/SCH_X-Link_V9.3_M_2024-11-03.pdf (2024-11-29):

IO电压缓冲 | Vref缓冲

# 接口下拉电阻

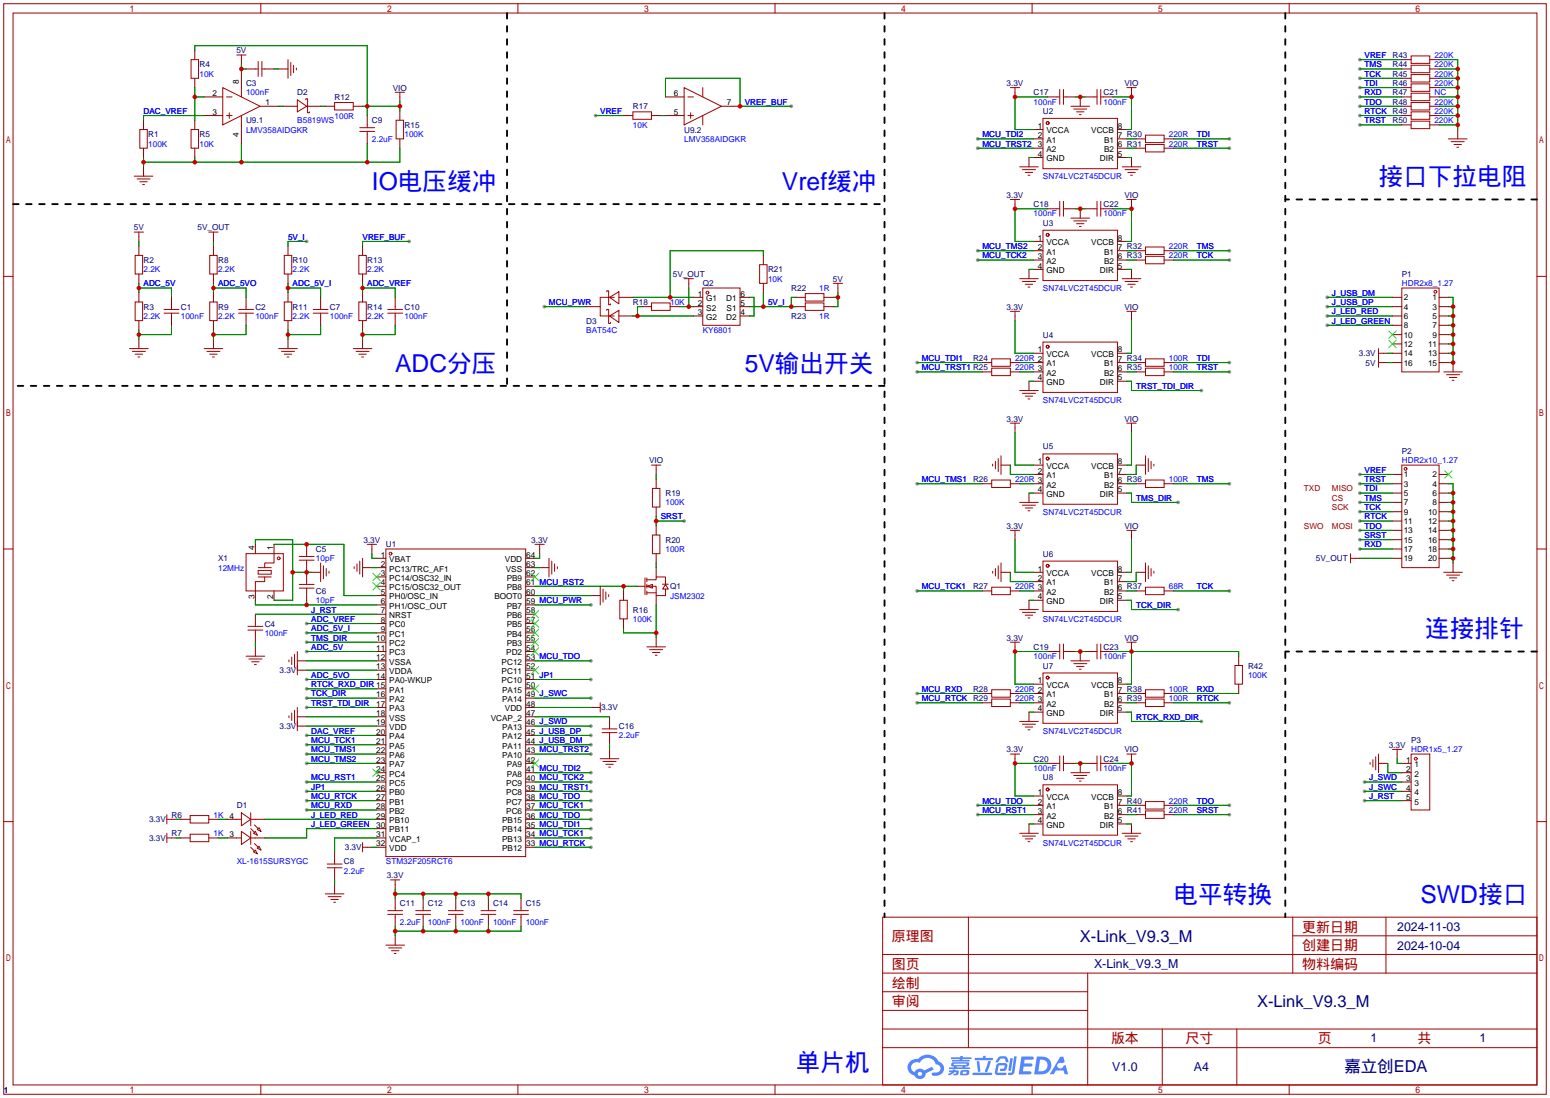
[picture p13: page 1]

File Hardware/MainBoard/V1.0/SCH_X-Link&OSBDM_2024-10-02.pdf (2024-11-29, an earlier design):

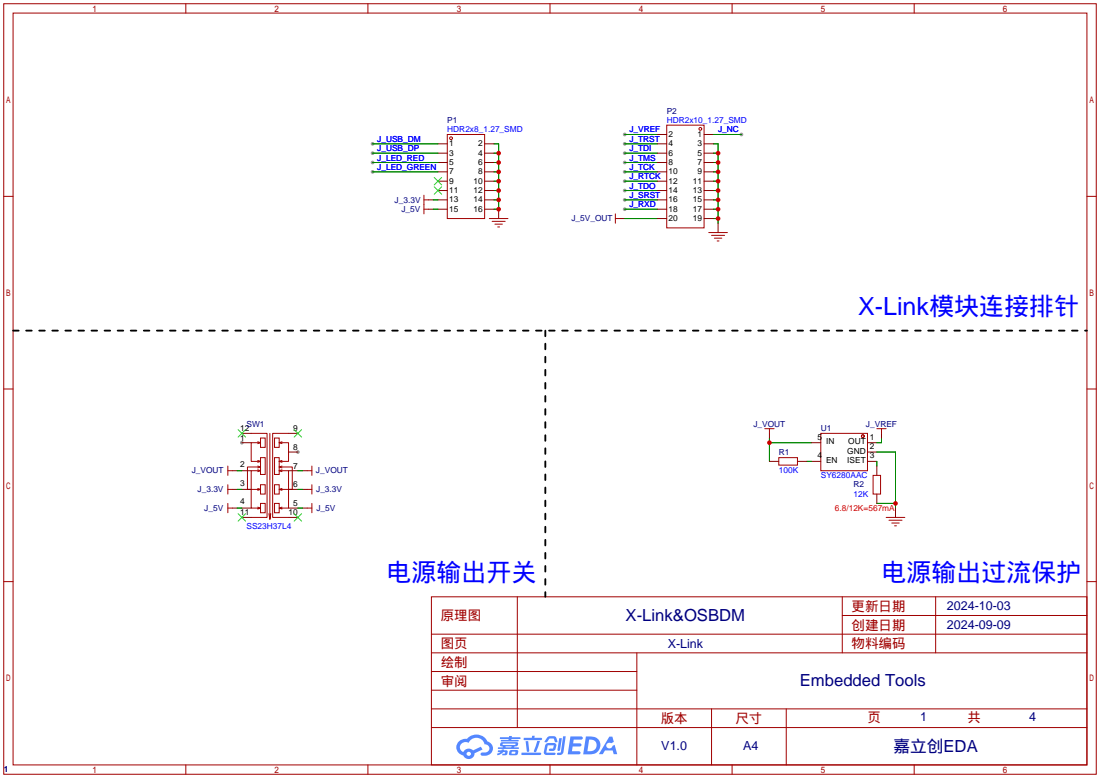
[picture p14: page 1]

IO电压缓冲 | Vref缓冲 | 输出配电开关

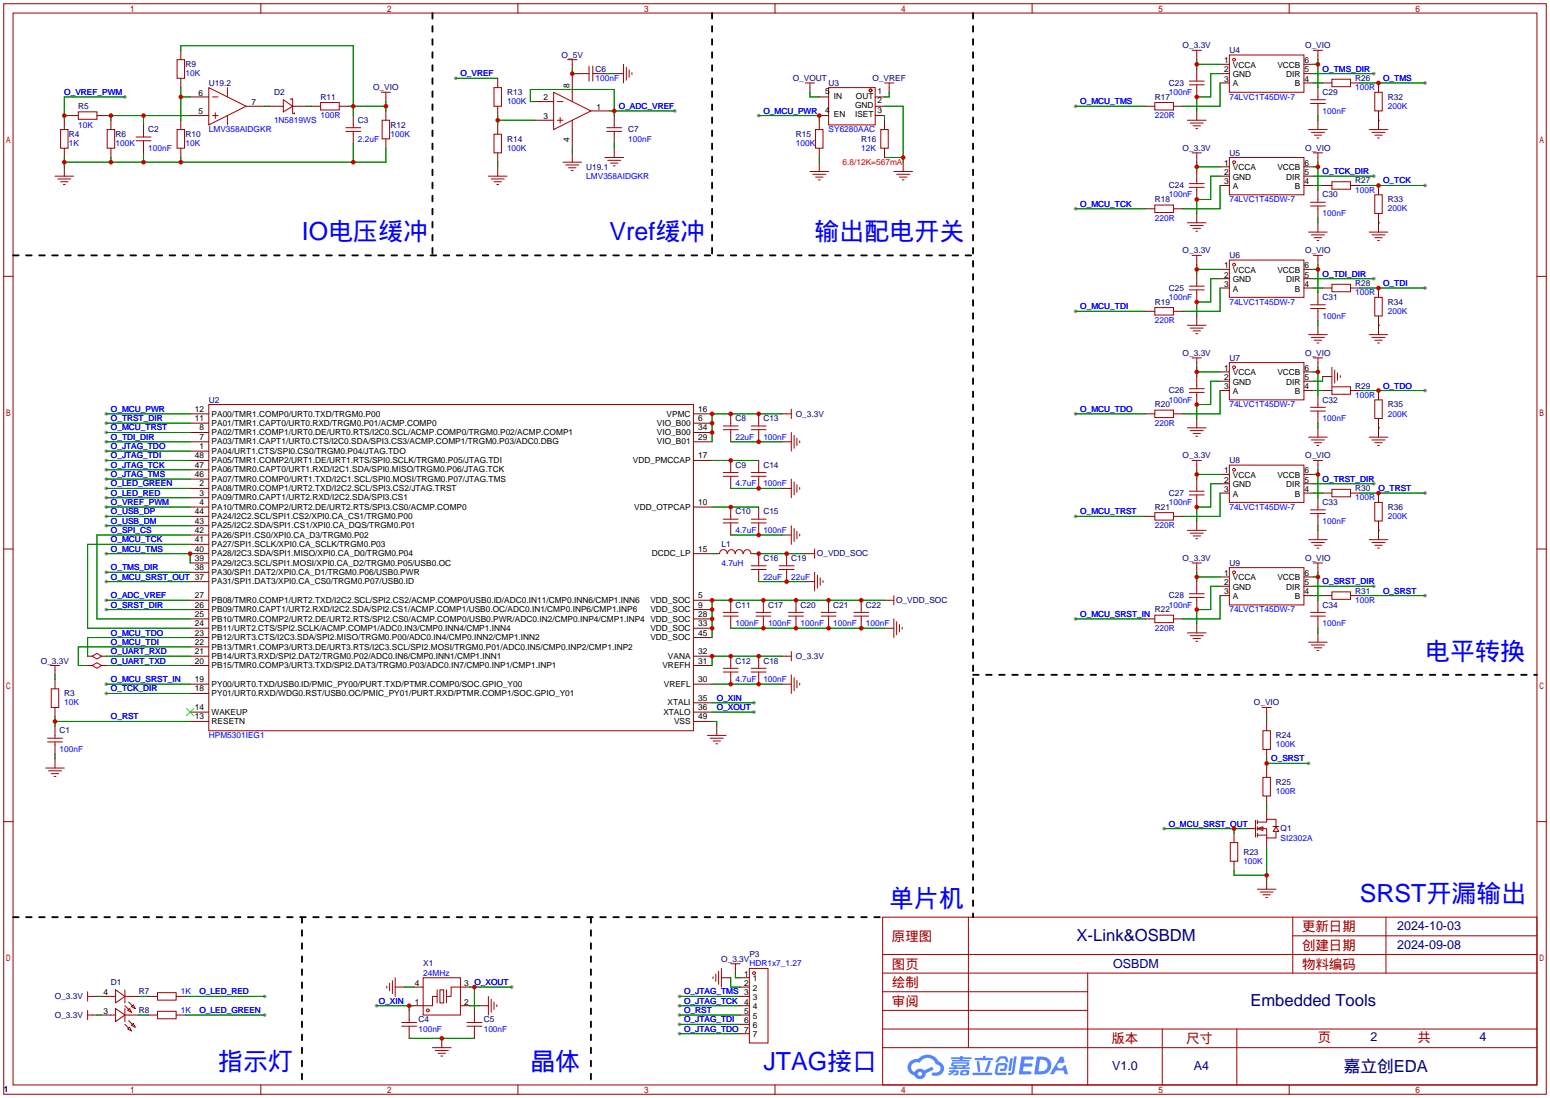
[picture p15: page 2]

PA01/TMR1.CAPT0/URT0.RXD/TRGM0.P01/ACMP.COMP0 11 PA00/TMR1.COMP0/URT0.TXD/TRGM0.P00 12
PA02/TMR1.COMP1/URT0.DE/URT0.RTS/I2C0.SCL/ACMP.COMP0/TRGM0.P02/ACMP.COMP1 8
PA03/TMR1.CAPT1/URT0.CTS/I2C0.SDA/SPI3.CS3/ACMP.COMP1/TRGM0.P03/ADC0.DBG 7
PA07/TMR0.COMP0/URT1.TXD/I2C1.SCL/SPI0.MOSI/TRGM0.P07/JTAG.TMS 46 PA06/TMR0.CAPT0/URT1.RXD/I2C1.SDA/SPI0.MISO/TRGM0.P06/JTAG.TCK 47 PA05/TMR1.COMP2/URT1.DE/URT1.RTS/SPI0.SCLK/TRGM0.P05/JTAG.TDI 48 PA04/URT1.CTS/SPI0.CS0/TRGM0.P04/JTAG.TDO 1

PA08/TMR0.COMP1/URT2.TXD/I2C2.SCL/SPI3.CS2/JTAG.TRST 2
PA09/TMR0.CAPT1/URT2.RXD/I2C2.SDA/SPI3.CS1 3
PA31/SPI1.DAT3/XPI0.CA_CS0/TRGM0.P07/USB0.ID 37 PA30/SPI1.DAT2/XPI0.CA_D1/TRGM0.P06/USB0.PWR 38 PA29/I2C3.SCL/SPI1.MOSI/XPI0.CA_D2/TRGM0.P05/USB0.OC 39 PA28/I2C3.SDA/SPI1.MISO/XPI0.CA_D0/TRGM0.P04 40 PA27/SPI1.SCLK/XPI0.CA_SCLK/TRGM0.P03 41 PA26/SPI1.CS0/XPI0.CA_D3/TRGM0.P02 42 PA25/I2C2.SDA/SPI1.CS1/XPI0.CA_DQS/TRGM0.P01 43 PA24/I2C2.SCL/SPI1.CS2/XPI0.CA_CS1/TRGM0.P00 44 PA10/TMR0.COMP2/URT2.DE/URT2.RTS/SPI3.CS0/ACMP.COMP0 4

PB15/TMR0.COMP3/URT3.TXD/SPI2.DAT3/TRGM0.P03/ADC0.IN7/CMP0.INP1/CMP1.INP1 20 PB14/URT3.RXD/SPI2.DAT2/TRGM0.P02/ADC0.IN6/CMP0.INN1/CMP1.INN1 21 PB13/TMR1.COMP3/URT3.DE/URT3.RTS/I2C3.SCL/SPI2.MOSI/TRGM0.P01/ADC0.IN5/CMP0.INP2/CMP1.INP2 22 PB12/URT3.CTS/I2C3.SDA/SPI2.MISO/TRGM0.P00/ADC0.IN4/CMP0.INN2/CMP1.INN2 23 PB11/URT2.CTS/SPI2.SCLK/ACMP.COMP1/ADC0.IN3/CMP0.INN4/CMP1.INN4 24 PB10/TMR0.COMP2/URT2.DE/URT2.RTS/SPI2.CS0/ACMP.COMP0/USB0.PWR/ADC0.IN2/CMP0.INP4/CMP1.INP4 25 PB09/TMR0.CAPT1/URT2.RXD/I2C2.SDA/SPI2.CS1/ACMP.COMP1/USB0.OC/ADC0.IN1/CMP0.INP6/CMP1.INP6 26 PB08/TMR0.COMP1/URT2.TXD/I2C2.SCL/SPI2.CS2/ACMP.COMP0/USB0.ID/ADC0.IN11/CMP0.INN6/CMP1.INN6 27

PY01/URT0.RXD/WDG0.RST/USB0.OC/PMIC_PY01/PURT.RXD/PTMR.COMP1/SOC.GPIO_Y01 18 PY00/URT0.TXD/USB0.ID/PMIC_PY00/PURT.TXD/PTMR.COMP0/SOC.GPIO_Y00 19

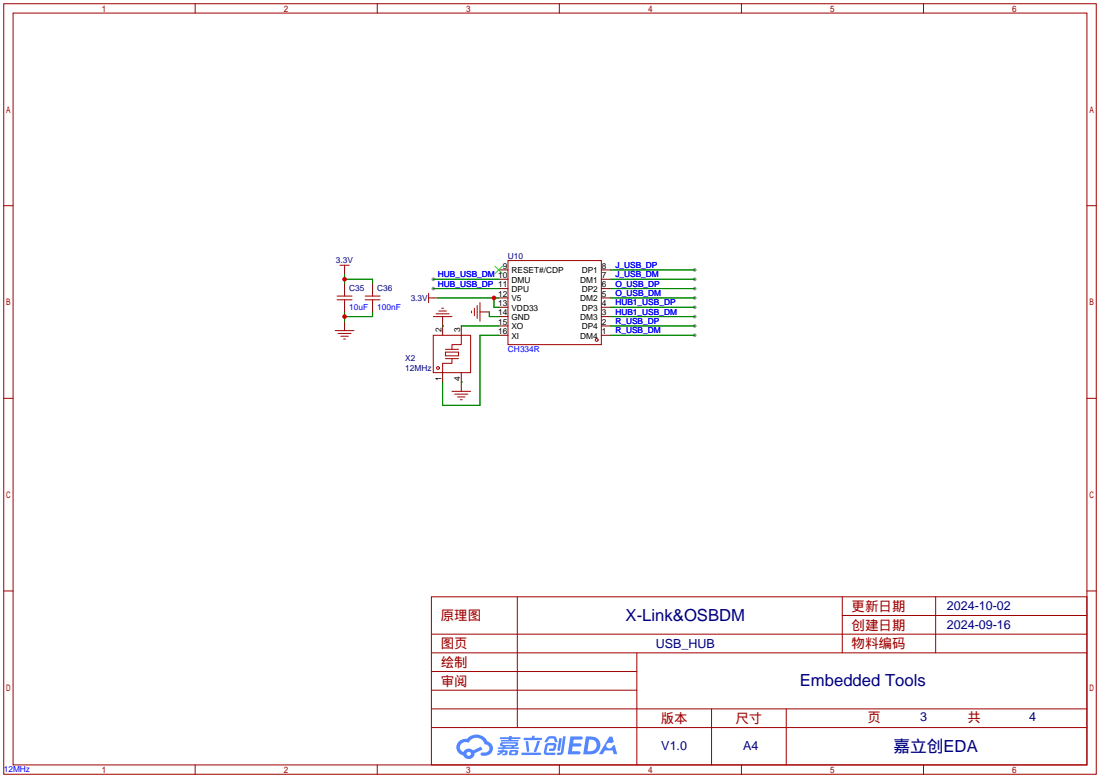
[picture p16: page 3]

1.8V电源 | 隔离电源 电源/USB跳线

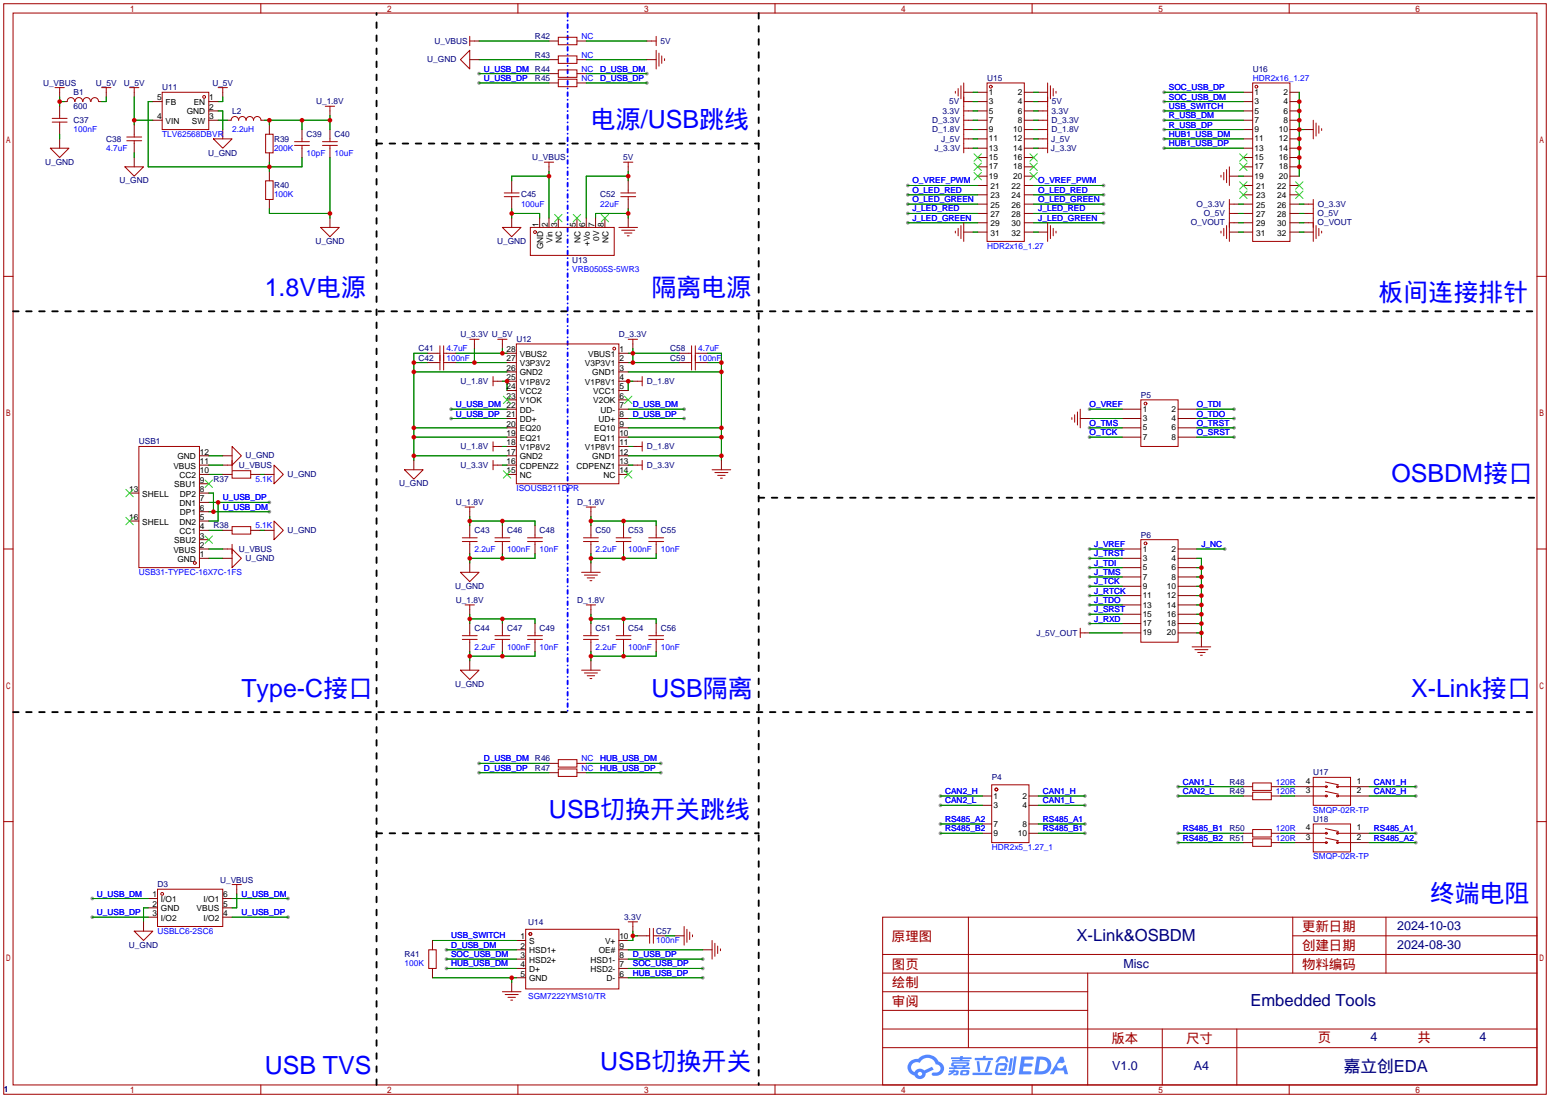
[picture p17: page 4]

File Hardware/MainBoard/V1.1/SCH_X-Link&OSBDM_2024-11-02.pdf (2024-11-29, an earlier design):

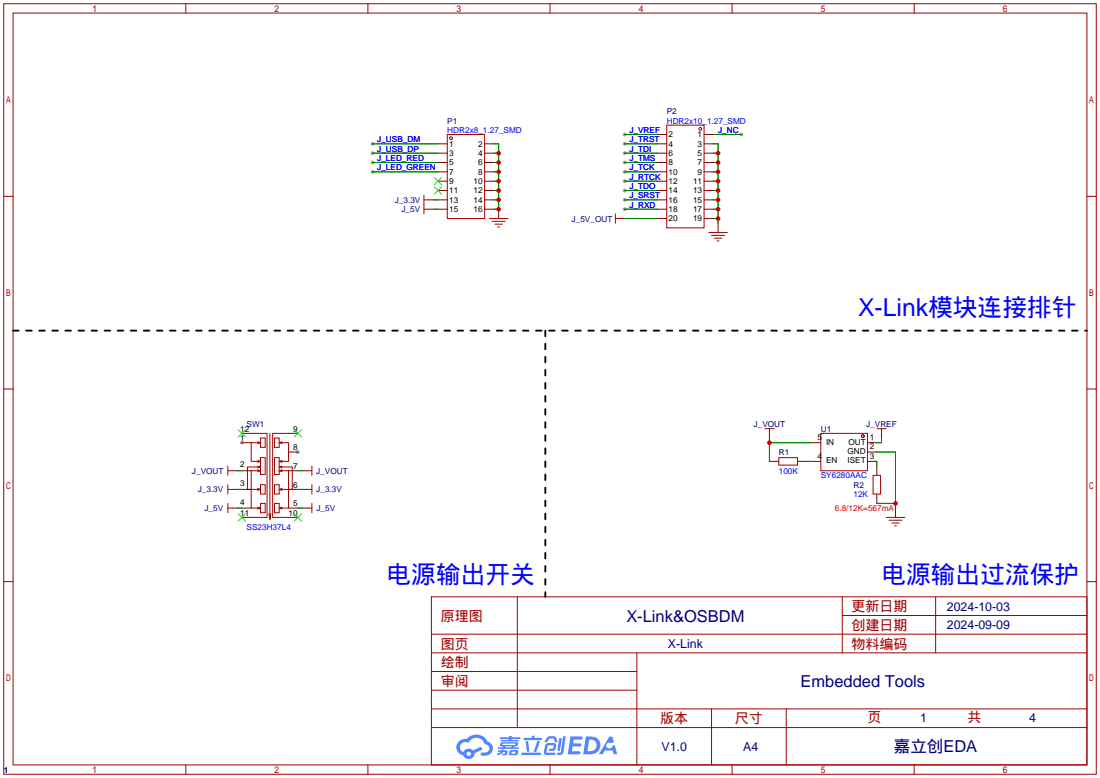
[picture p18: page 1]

IO电压缓冲 | Vref缓冲 | 输出配电开关


PA01/TMR1.CAPT0/URT0.RXD/TRGM0.P01/ACMP.COMP0 11 PA00/TMR1.COMP0/URT0.TXD/TRGM0.P00 12
PA02/TMR1.COMP1/URT0.DE/URT0.RTS/I2C0.SCL/ACMP.COMP0/TRGM0.P02/ACMP.COMP1 8
PA03/TMR1.CAPT1/URT0.CTS/I2C0.SDA/SPI3.CS3/ACMP.COMP1/TRGM0.P03/ADC0.DBG 7
PA07/TMR0.COMP0/URT1.TXD/I2C1.SCL/SPI0.MOSI/TRGM0.P07/JTAG.TMS 46 PA06/TMR0.CAPT0/URT1.RXD/I2C1.SDA/SPI0.MISO/TRGM0.P06/JTAG.TCK 47 PA05/TMR1.COMP2/URT1.DE/URT1.RTS/SPI0.SCLK/TRGM0.P05/JTAG.TDI 48 PA04/URT1.CTS/SPI0.CS0/TRGM0.P04/JTAG.TDO 1

PA08/TMR0.COMP1/URT2.TXD/I2C2.SCL/SPI3.CS2/JTAG.TRST 2
PA09/TMR0.CAPT1/URT2.RXD/I2C2.SDA/SPI3.CS1 3
PA31/SPI1.DAT3/XPI0.CA_CS0/TRGM0.P07/USB0.ID 37 PA30/SPI1.DAT2/XPI0.CA_D1/TRGM0.P06/USB0.PWR 38 PA29/I2C3.SCL/SPI1.MOSI/XPI0.CA_D2/TRGM0.P05/USB0.OC 39 PA28/I2C3.SDA/SPI1.MISO/XPI0.CA_D0/TRGM0.P04 40 PA27/SPI1.SCLK/XPI0.CA_SCLK/TRGM0.P03 41 PA26/SPI1.CS0/XPI0.CA_D3/TRGM0.P02 42 PA25/I2C2.SDA/SPI1.CS1/XPI0.CA_DQS/TRGM0.P01 43 PA24/I2C2.SCL/SPI1.CS2/XPI0.CA_CS1/TRGM0.P00 44 PA10/TMR0.COMP2/URT2.DE/URT2.RTS/SPI3.CS0/ACMP.COMP0 4

PB15/TMR0.COMP3/URT3.TXD/SPI2.DAT3/TRGM0.P03/ADC0.IN7/CMP0.INP1/CMP1.INP1 20 PB14/URT3.RXD/SPI2.DAT2/TRGM0.P02/ADC0.IN6/CMP0.INN1/CMP1.INN1 21 PB13/TMR1.COMP3/URT3.DE/URT3.RTS/I2C3.SCL/SPI2.MOSI/TRGM0.P01/ADC0.IN5/CMP0.INP2/CMP1.INP2 22 PB12/URT3.CTS/I2C3.SDA/SPI2.MISO/TRGM0.P00/ADC0.IN4/CMP0.INN2/CMP1.INN2 23 PB11/URT2.CTS/SPI2.SCLK/ACMP.COMP1/ADC0.IN3/CMP0.INN4/CMP1.INN4 24 PB10/TMR0.COMP2/URT2.DE/URT2.RTS/SPI2.CS0/ACMP.COMP0/USB0.PWR/ADC0.IN2/CMP0.INP4/CMP1.INP4 25 PB09/TMR0.CAPT1/URT2.RXD/I2C2.SDA/SPI2.CS1/ACMP.COMP1/USB0.OC/ADC0.IN1/CMP0.INP6/CMP1.INP6 26 PB08/TMR0.COMP1/URT2.TXD/I2C2.SCL/SPI2.CS2/ACMP.COMP0/USB0.ID/ADC0.IN11/CMP0.INN6/CMP1.INN6 27

PY01/URT0.RXD/WDG0.RST/USB0.OC/PMIC_PY01/PURT.RXD/PTMR.COMP1/SOC.GPIO_Y01 18 PY00/URT0.TXD/USB0.ID/PMIC_PY00/PURT.TXD/PTMR.COMP0/SOC.GPIO_Y00 19


1.8V电源 | 隔离电源 电源/USB跳线


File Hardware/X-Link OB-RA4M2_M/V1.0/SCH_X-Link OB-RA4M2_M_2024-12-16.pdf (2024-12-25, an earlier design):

# Vref缓冲


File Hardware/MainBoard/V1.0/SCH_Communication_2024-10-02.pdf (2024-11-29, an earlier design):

# CAN1


C3 | 100nF
C4 | 100nF

# RS485_1

# 信号隔离





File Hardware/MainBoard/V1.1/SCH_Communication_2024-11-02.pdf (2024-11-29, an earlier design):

# CAN1


C3 | 100nF
C4 | 100nF

# RS485_1

# 信号隔离





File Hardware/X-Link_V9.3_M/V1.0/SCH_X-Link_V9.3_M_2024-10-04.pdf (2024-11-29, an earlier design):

IO电压缓冲 | Vref缓冲

# 接口下拉电阻
